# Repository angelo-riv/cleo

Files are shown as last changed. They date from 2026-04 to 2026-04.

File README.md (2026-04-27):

# Quadruped Robot

## Photos

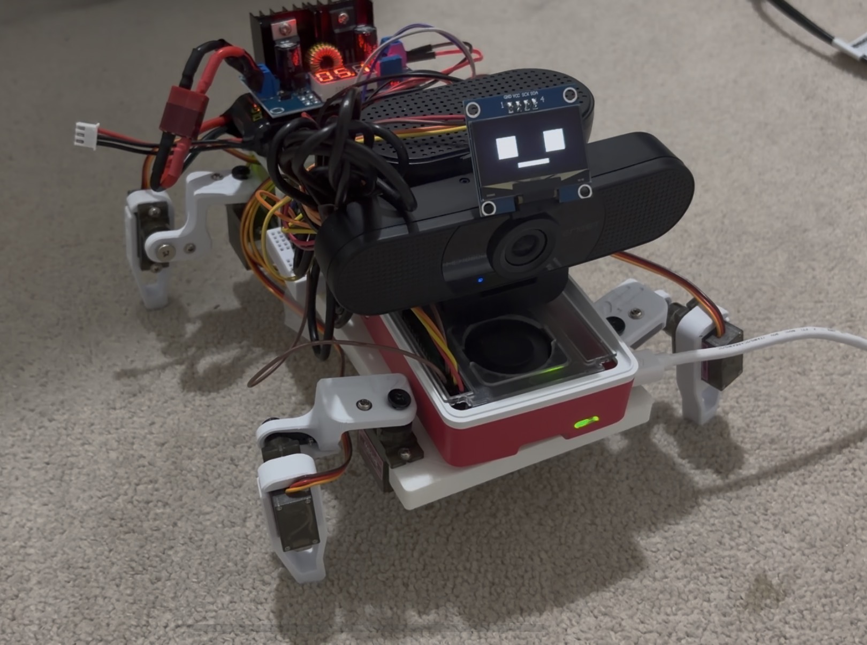
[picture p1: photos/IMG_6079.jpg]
Cleo robot photo


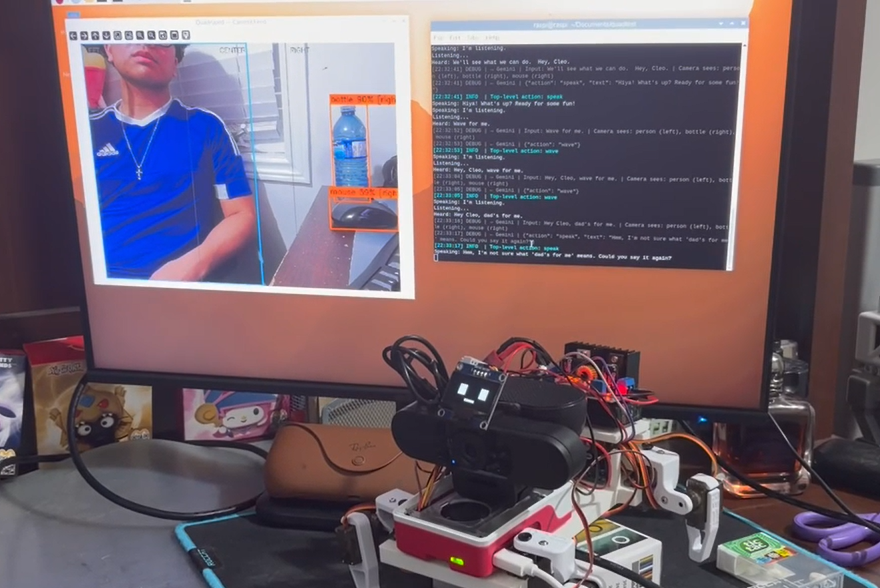
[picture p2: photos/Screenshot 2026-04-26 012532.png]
Cleo screenshot


An autonomous 4-legged robot powered by a Raspberry Pi and Google Gemini AI. Speak to it, give it missions, and it walks, looks, thinks, and talks back. Supports multiple AI personality modes switchable by voice at any time.

> For full software architecture, data flows, and code documentation see [ARCHITECTURE.md](ARCHITECTURE.md).

---

## Features

- **Voice control** — speak naturally to give missions or have a conversation
- **AI brain** — Google Gemini decides every action based on what you say and what the camera sees
- **Object detection** — camera identifies 20 object types and their position (left / center / right)
- **Walking** — creep gait using 8 servo motors across 4 legs
- **Expressive face** — OLED display shows animated faces that change based on what the robot is doing
- **Sensor awareness** — live temperature, humidity, and motion data fed to the AI
- **Switchable modes** — say "switch to search and rescue mode" and the AI's entire personality changes
- **Manual control** — keyboard-driven demo mode with live annotated camera feed for presentations

---

## Technologies Used

| Technology | What it does in this project |
|---|---|
| **Python 3** | Entire codebase |
| **Google Gemini 2.5 Flash** | AI decision engine — receives text descriptions of what the robot sees and returns the next action as JSON |
| **faster-whisper (Whisper tiny.en)** | Speech-to-text — runs fully offline on the Pi, no API key needed |
| **gTTS (Google Text-to-Speech)** | Text-to-speech — converts Gemini's responses to audio, requires internet |
| **MobileNet SSD (OpenCV DNN)** | Object detection — runs locally on the Pi, identifies objects in camera frames |
| **USB Webcam or Pi Camera** | Captures frames for object detection |
| **PCA9685 PWM driver** | Controls all 8 servo motors over I2C |
| **luma.oled + PIL** | Draws bitmap faces on the SSD1306 OLED display |
| **Adafruit CircuitPython** | Servo motor and DHT11 sensor drivers |
| **sounddevice** | Records microphone audio |
| **pygame** | Plays TTS audio through the speaker |
| **python-dotenv** | Loads API keys securely from `.env` |

---

## Hardware Required

| Part | Purpose |
|---|---|
| Raspberry Pi 4 (or 3B+) | Main computer |
| PCA9685 PWM driver board | Controls 8 servos over I2C |
| 8x servo motors | 2 per leg — hip + knee |
| USB webcam or Pi Camera Module | Object detection |
| USB microphone | Voice input |
| Speaker + USB audio adapter | Voice output |
| SSD1306 OLED display (128×64) | Face display |
| DHT11 sensor *(optional)* | Activates environment mode |
| PIR motion sensor *(optional)* | Activates security mode |
| 5V power supply | Pi + servos (servos draw significant current) |

### Wiring

| Component | Connection |
|---|---|
| PCA9685 | I2C — SDA = GPIO 2, SCL = GPIO 3, address `0x40` |
| OLED display | I2C — same bus, address `0x3C` |
| DHT11 | GPIO pin 27 |
| PIR sensor | GPIO pin 17 |
| USB webcam | Any USB port |
| USB mic + speaker | USB ports |

---

## Modes

The robot scans for attached sensor modules at boot and starts in the matching mode. Switch anytime by voice.

| Mode | Activates when | AI personality |
|---|---|---|
| `general` | No module detected | Helpful companion, conversational |
| `security` | PIR sensor on GPIO 17 | Vigilant patrol robot, threat-aware |
| `environment` | DHT11 on I2C `0x44` | Environmental monitor, flags temp/humidity anomalies |
| `search_rescue` | Voice command only | Emergency responder, systematic people-search |

**To switch by voice** — say it naturally, Gemini understands intent:
- *"Switch to search and rescue mode"*
- *"Go into security mode"*
- *"Back to general mode"*

---

## OLED Faces

The display shows animated bitmap faces. Each state has multiple variants that cycle randomly — no two consecutive looks the same.

| State | Variants | When shown |
|---|---|---|
| `idle` | Open eyes, half-asleep, mid-blink | Waiting for input |
| `thinking` | Squinted, looking sideways, looking up | Gemini is processing |
| `searching` | One-eye squint, both-eyes-wide alert | On a mission |
| `happy` | Standard smile, wink, huge eyes, star eyes, excited | Mission complete |
| `surprised` | Wide O-eyes + hollow O-mouth | Triggered manually |

---

## Setup

There are two setup paths depending on what hardware you have available:

- **[Full setup](#full-setup)** — complete robot with servos, OLED, and sensors
- **[Camera / mic / speaker only](#cameramicspeaker-only-setup)** — test voice and vision without any I2C hardware

---

## Full Setup

### 1. Flash Raspberry Pi OS

Use **Raspberry Pi Imager** → **Raspberry Pi OS (64-bit)**. In the advanced settings (gear icon):
- Set hostname, username, password
- Enable SSH
- Enter your Wi-Fi credentials

### 2. SSH into the Pi

Find the Pi's IP address from your router's device list, or from the Pi directly if you have a monitor:

```bash
hostname -I
```

Then connect from your computer:

```bash
ssh <username>@<ip-address>
# Example: ssh pi@192.168.1.42
```

If you set a hostname in Raspberry Pi Imager (e.g. `quadruped`), you can also use:

```bash
ssh <username>@quadruped.local
```

Accept the fingerprint prompt the first time. Enter the password you set in Imager.

> **Windows users** — SSH is built into PowerShell and Command Prompt on Windows 10+. No extra software needed.

### 3. Enable I2C

```bash
sudo raspi-config
```

Under **Interface Options** enable **I2C**, then reboot:

```bash
sudo reboot
```

### 4. Get the project

```bash
git clone <your-repo-url> ~/quadruped
cd ~/quadruped
```

### 5. Set up SSH key for GitHub (if cloning via SSH)

```bash
ssh-keygen -t ed25519 -C "your@email.com"
cat ~/.ssh/id_ed25519.pub
```

Copy the output and add it to GitHub under **Settings → SSH and GPG keys → New SSH key**.

Verify it works:

```bash
ssh -T git@github.com
```

### 6. Configure `.env` (Gemma 4 primary, Gemini optional fallback)

```bash
nano .env
```

```
# Primary (Ollama / Gemma 4)
CLEO_MODEL=gemma4
OLLAMA_BASE_URL=http://localhost:11434

# Optional fallback (Gemini) — only used if Ollama fails
# GEMINI_API_KEY=your_actual_key_here
# GEMINI_MODEL=gemini-2.5-flash
```

If you want the Gemini fallback, get a free key at [https://aistudio.google.com/app/apikey](https://aistudio.google.com/app/apikey). Save with `Ctrl+X` → `Y` → `Enter`.

### 7. Create a virtual environment and install dependencies

Raspberry Pi OS Trixie requires a venv — do not skip this:

```bash
python3 -m venv venv
source venv/bin/activate

sudo apt update
sudo apt install -y python3-dev portaudio19-dev libgpiod2

pip install \
  adafruit-circuitpython-pca9685 \
  adafruit-circuitpython-motor \
  adafruit-circuitpython-dht \
  opencv-python \
  luma.oled \
  Pillow \
  faster-whisper \
  sounddevice \
  gTTS \
  pygame \
  python-dotenv \
  RPi.GPIO
```

To enable the optional Gemini fallback:

```bash
pip install google-generativeai
```

> You must run `source venv/bin/activate` at the start of every new SSH session before running the robot.

### 8. Download the vision model

```bash
mkdir -p models

# Prototxt (~29 KB)
wget -O models/MobileNetSSD_deploy.prototxt \
  https://raw.githubusercontent.com/djmv/MobilNet_SSD_opencv/master/MobileNetSSD_deploy.prototxt

# Caffemodel (~23 MB) — use gdown for reliable Google Drive download
pip install gdown
gdown --id 0B3gersZ2cHIxRm5PMWRoTkdHdHc -O models/MobileNetSSD_deploy.caffemodel
```

Verify both files downloaded correctly:

```bash
ls -lh models/
# prototxt should be ~29K, caffemodel should be ~23M
```

### 9. Test audio

```bash
arecord -l    # list recording devices
aplay -l      # list playback devices
```

Test record and playback using the specific card numbers shown:

```bash
arecord -D plughw:<mic-card>,0 -d 3 -f cd test.wav && aplay -D plughw:<speaker-card>,0 test.wav
```

Set the default speaker so pygame picks it up:

```bash
nano ~/.asoundrc
```

```
defaults.pcm.card <speaker-card>
defaults.ctl.card <speaker-card>
```

If the wrong mic is selected, set `MIC_DEVICE_INDEX` in `config.py` to the correct card number.

### 10. Run

```bash
python3 main.py
```

The robot stands up and says "I'm listening."

### 11. Auto-start on boot *(optional)*

```bash
sudo nano /etc/rc.local
```

Add before `exit 0`:

```bash
cd /home/pi/quadruped && source venv/bin/activate && python3 main.py >> /home/pi/quadruped/robot.log 2>&1 &
```

---

## Camera / Mic / Speaker Only Setup

Use this path to test voice and vision without any I2C hardware (no servo driver, no OLED, no sensors). The robot runs in mock mode — servo and display commands print to the terminal instead of hitting hardware.

### 1. Flash, SSH, and get the project

Follow steps 1–6 from [Full Setup](#full-setup) above (flash OS, SSH in, get the project, add API key). Skip the raspi-config I2C step.

### 2. Create a virtual environment and install dependencies

```bash
python3 -m venv venv
source venv/bin/activate

sudo apt update
sudo apt install -y python3-dev portaudio19-dev

pip install \
  opencv-python \
  luma.oled \
  Pillow \
  faster-whisper \
  sounddevice \
  gTTS \
  pygame \
  google-generativeai \
  python-dotenv
```

### 3. Download the vision model

```bash
mkdir -p models

wget -O models/MobileNetSSD_deploy.prototxt \
  https://raw.githubusercontent.com/djmv/MobilNet_SSD_opencv/master/MobileNetSSD_deploy.prototxt

pip install gdown
gdown --id 0B3gersZ2cHIxRm5PMWRoTkdHdHc -O models/MobileNetSSD_deploy.caffemodel
```

Verify sizes (`prototxt` ~29K, `caffemodel` ~23M):

```bash
ls -lh models/
```

### 4. Enable mock mode

Open `config.py` and set:

```python
MOCK_SERVOS = True      # skips all I2C/servo/GPIO hardware
SHOW_CAMERA_FEED = False  # no display window (required when running over SSH)
CLEO_MODEL = "gemma4"
OLLAMA_BASE_URL = "http://localhost:11434"
# Optional fallback:
# GEMINI_API_KEY = "..."
# GEMINI_MODEL = "gemini-2.5-flash"
```

### 5. Test audio

```bash
arecord -l    # find your mic card number
aplay -l      # find your speaker card number
```

```bash
arecord -D plughw:<mic-card>,0 -d 3 -f cd test.wav && aplay -D plughw:<speaker-card>,0 test.wav
```

Set the default speaker:

```bash
nano ~/.asoundrc
```

```
defaults.pcm.card <speaker-card>
defaults.ctl.card <speaker-card>
```

Set `MIC_DEVICE_INDEX` in `config.py` to your mic's card number if needed.

### 6. Test camera and object detection

```bash
python3 -c "
import cv2

net = cv2.dnn.readNetFromCaffe('models/MobileNetSSD_deploy.prototxt', 'models/MobileNetSSD_deploy.caffemodel')
CLASSES = ['background','aeroplane','bicycle','bird','boat','bottle','bus','car',
           'cat','chair','cow','diningtable','dog','horse','motorbike','person',
           'pottedplant','sheep','sofa','train','tvmonitor']

cam = cv2.VideoCapture(0)
ret, frame = cam.read()
if not ret:
    print('ERROR: camera not readable')
else:
    print(f'Frame captured: {frame.shape}')
    blob = cv2.dnn.blobFromImage(cv2.resize(frame, (300,300)), 0.007843, (300,300), 127.5)
    net.setInput(blob)
    out = net.forward()
    found = [(CLASSES[int(out[0,0,i,1])], f'{out[0,0,i,2]:.0%}')
             for i in range(out.shape[2]) if out[0,0,i,2] > 0.5]
    print('Detections:', found if found else 'nothing above 50% confidence')
cam.release()
"
```

### 7. Run

```bash
python3 main.py
```

Servo and OLED commands will print as `[MOCK]` lines. Everything else (voice, camera, Gemini) runs for real.

---

## Running the Demo (Manual Control)

For presentations and demos, run `manual_control.py` instead of `main.py`. This opens a live annotated camera window on a connected monitor and lets you drive the robot with your keyboard.

```bash
python3 manual_control.py
```

> Manual control requires a connected monitor — it cannot run headless over SSH.

**Click the camera window first to capture keyboard focus, then use these controls:**

| Key | Action |
|---|---|
| `W` | Walk forward one step |
| `A` | Turn left |
| `D` | Turn right |
| `S` | Stand / stop |
| `SPACE` | Ask Gemini what it currently sees — speaks the answer aloud and shows it on screen |
| `1` | Switch to General mode |
| `2` | Switch to Security mode |
| `3` | Switch to Environment mode |
| `4` | Switch to Search & Rescue mode |
| `F` | Cycle the OLED to a random happy face |
| `Q` or `ESC` | Quit cleanly |

The camera window overlays the current mode, last action, last LLM response, and live sensor readings directly on the feed.

---

## Configuration Reference

| Setting | What it controls | Default |
|---|---|---|
| `OLLAMA_BASE_URL` | Ollama server URL (primary LLM) | `http://localhost:11434` |
| `CLEO_MODEL` | Ollama model name (primary LLM) | `gemma4` |
| `GEMINI_API_KEY` | Enables Gemini fallback if set | *(blank)* |
| `GEMINI_MODEL` | Gemini model used for fallback | `gemini-2.5-flash` |
| `WHISPER_MODEL` | STT model size | `tiny.en` |
| `MIC_DEVICE_INDEX` | USB mic card number (`None` = auto) | `None` |
| `CAMERA_RESOLUTION` | Capture resolution | `(640, 480)` |
| `DETECTION_CONFIDENCE_THRESHOLD` | Min confidence to report an object | `0.5` |
| `SHOW_CAMERA_FEED` | Show annotated feed on monitor (disable over SSH) | `True` |
| `MOCK_SERVOS` | Skip all I2C/servo/GPIO hardware | `False` |
| `GAIT_STEP_ANGLE` | Hip swing per step (degrees) | `20` |
| `GAIT_LIFT_ANGLE` | Knee lift per step (degrees) | `30` |
| `GAIT_STEP_DELAY` | Pause between gait phases (seconds) | `0.15` |
| `PCA9685_ADDRESS` | I2C address of servo driver | `0x40` |
| `OLED_I2C_ADDRESS` | I2C address of OLED | `0x3C` |
| `PIR_GPIO_PIN` | GPIO pin for PIR sensor | `17` |
| `DHT11_GPIO_PIN` | GPIO pin for DHT11 sensor | `27` |

---

## Security Notes

- `.env` is in `.gitignore` — it will never be committed
- Gemini fallback is optional — if `GEMINI_API_KEY` is missing, the robot still runs (Gemma 4 via Ollama only)
- Never paste your API key into chat, issues, or log files
- `robot.log` does not record API keys or audio transcripts

---

## Known Limitations

- **gTTS needs internet** — for fully offline TTS, swap `gTTS` for `pyttsx3` in `voice/tts.py`
- **Whisper has a 1–2s delay** — after you stop speaking, transcription takes a moment on Pi 4
- **MobileNet SSD recognises 20 object classes only** — it cannot identify objects outside that list
- **LLM chat history is in-memory** — resets on restart or mode change
- **`SHOW_CAMERA_FEED = True` crashes over SSH** — set it to `False` when running headless

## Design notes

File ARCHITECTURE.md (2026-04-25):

# Software Architecture

Technical documentation for the quadruped robot codebase — data flows, execution loops, component responsibilities, and design decisions.

> For setup instructions, hardware, features, and demo controls see [README.md](README.md).

---

## System Layers

```
╔══════════════════════════════════════════════════════════════════╗
║                         YOU (the human)                          ║
║                  speak ↓              ↑ hear                     ║
╚══════════════════════════╤═══════════════════════════════════════╝
                           │
╔══════════════════════════▼═══════════════════════════════════════╗
║                      HARDWARE LAYER                              ║
║                                                                  ║
║  [USB Mic] [Pi Camera] [PIR Sensor] [DHT11] [Speaker]           ║
║  [8x Servos via PCA9685]  [SSD1306 OLED]                        ║
╚══════════════════════════╤═══════════════════════════════════════╝
                           │ GPIO / I2C / CSI / USB
╔══════════════════════════▼═══════════════════════════════════════╗
║                      SOFTWARE LAYER (Python)                     ║
║                                                                  ║
║  ┌──────────────────────────────────────────────────────────┐   ║
║  │                    brain/agent.py                         │   ║
║  │             (master orchestrator — runs forever)          │   ║
║  └───┬──────────┬───────────┬──────────┬──────────┬─────────┘   ║
║      │          │           │          │          │              ║
║  ┌───▼───┐  ┌───▼───┐  ┌───▼───┐  ┌───▼───┐  ┌───▼──────────┐ ║
║  │voice/ │  │vision/│  │motion/│  │display│  │  modules/    │ ║
║  │stt.py │  │detect │  │gait.py│  │oled.py│  │  pir.py      │ ║
║  │tts.py │  │or.py  │  │servo_ │  │faces/ │  │  dht11.py    │ ║
║  │       │  │       │  │ctrl.py│  │       │  │  detector.py │ ║
║  └───┬───┘  └───┬───┘  └───────┘  └───────┘  └──────────────┘ ║
║      │          │                                               ║
║  ┌───▼──────────▼─────────────────────────────────────────┐    ║
║  │                    brain/llm.py                         │    ║
║  │   (packages inputs → sends to Gemini → parses JSON)    │    ║
║  └───────────────────────────┬─────────────────────────────┘   ║
╚══════════════════════════════╤══════════════════════════════════╝
                               │ HTTPS (Gemini API)
╔══════════════════════════════▼═══════════════════════════════════╗
║                      GOOGLE GEMINI (cloud AI)                    ║
║   Receives: user speech + camera detections + sensor readings    ║
║   Returns:  one JSON action  e.g. {"action": "walk_forward"}     ║
╚══════════════════════════════════════════════════════════════════╝
```

---

## Project Structure

```
quadruped/
├── main.py                  # Entry point — creates and runs Agent
├── manual_control.py        # Demo mode — keyboard control + live camera feed
├── config.py                # All settings, loaded from .env + hardware constants
├── setup.sh                 # One-time install script for Raspberry Pi
├── .env                     # Secret API keys (never committed)
├── .gitignore               # Excludes .env, model weights, pycache
│
├── brain/
│   ├── agent.py             # Master orchestrator — boot, main loop, mission loop
│   └── llm.py               # Gemini: mode prompts, persistent chat session, JSON parsing
│
├── motion/
│   ├── servo_controller.py  # Low-level: sets angles on individual joints via PCA9685
│   └── gait.py              # High-level: coordinates 4 legs for walking and turning
│
├── vision/
│   └── detector.py          # Pi Camera + MobileNet SSD: detects objects with position
│
├── voice/
│   ├── stt.py               # USB mic → Whisper AI → text (fully offline)
│   └── tts.py               # Text → Google TTS → speaker audio
│
├── display/
│   ├── oled.py              # Renders bitmap faces on SSD1306 OLED, random variant selection
│   └── faces/
│       ├── idle.py          # Open eyes, flat mouth
│       ├── idle_sleepy.py   # Half-closed eyes
│       ├── idle_blink.py    # Mid-blink slit eyes
│       ├── thinking.py      # Squinted eyes
│       ├── thinking_sideways.py  # Eyes shifted right
│       ├── thinking_up.py   # Eyes shifted upward
│       ├── searching.py     # One wide, one squinted
│       ├── searching_alert.py    # Both eyes wide open
│       ├── happy.py         # Standard smile
│       ├── happy_wink.py    # Wink + smile
│       ├── happy_big.py     # Oversized eyes + wide smile
│       ├── happy_star.py    # Cross/star-shaped eyes + smile
│       ├── excited.py       # Eyebrows + big eyes + extra-wide smile
│       └── surprised.py     # Huge square eyes + hollow O-mouth
│
├── modules/
│   ├── detector.py          # I2C bus scan at boot → returns starting mode string
│   ├── dht11.py             # DHT11 driver → {temperature, humidity}
│   └── pir.py               # PIR driver → motion_detected bool
│
└── utils/
    └── logger.py            # Colour-coded terminal logger with timestamps and levels
```

---

## Component Responsibilities

| File | Role | Inputs | Outputs |
|---|---|---|---|
| `main.py` | Entry point | — | Creates and runs `Agent` |
| `brain/agent.py` | Orchestrator | All sensor/voice/vision data | Commands to all subsystems |
| `brain/llm.py` | AI interface | Speech + detections + sensor data + mode | JSON action dict |
| `voice/stt.py` | Speech-to-text | USB mic audio (5s window) | Transcribed string |
| `voice/tts.py` | Text-to-speech | String | Audio played through speaker |
| `vision/detector.py` | Object detection | Camera frame | `[{label, position, confidence, bbox}]` |
| `motion/servo_controller.py` | Joint control | Joint name + angle | PWM signal via PCA9685 |
| `motion/gait.py` | Walking | Action string | Sequence of joint angle commands |
| `display/oled.py` | Face display | Face state string | Bitmap rendered to OLED |
| `modules/detector.py` | Mode detection | I2C bus scan | Mode string |
| `modules/pir.py` | Motion sensing | GPIO pin 17 | `True` / `False` |
| `modules/dht11.py` | Environment sensing | GPIO pin 27 | `{temperature, humidity}` |
| `utils/logger.py` | Logging | Message + level string | Colour-coded terminal line |
| `config.py` | Configuration | `.env` file | Constants used by all modules |

---

## Boot Sequence

```
python3 main.py
       │
       ▼
Agent.__init__()
       │
       ├──► ServoController()
       │         └── Connects to PCA9685 over I2C (address 0x40)
       │         └── Creates 8 servo objects (hips + knees for each leg)
       │
       ├──► GaitController(servo_controller)
       │         └── Stores servo reference, loads standing pose from config
       │
       ├──► VisionDetector()
       │         └── Loads MobileNet SSD model files into OpenCV DNN
       │         └── Starts Raspberry Pi Camera via picamera2
       │
       ├──► OLEDDisplay()
       │         └── Connects to SSD1306 over I2C (address 0x3C)
       │
       ├──► SpeechToText()
       │         └── Loads Whisper "tiny.en" model into CPU memory (~75MB)
       │
       ├──► TextToSpeech()
       │         └── Initialises pygame audio mixer
       │
       ├──► ModuleDetector()
       │         └── Scans I2C bus for known addresses
       │         └── Returns: "environment" (DHT11) | "security" (default)
       │
       ├──► PIRSensor()   [optional — skipped gracefully if absent]
       │         └── Configures GPIO pin 17 as input
       │
       └──► DHT11Sensor() [optional — skipped gracefully if absent]
                 └── Configures GPIO pin 27 as input

Agent.run()
       │
       ├──► sc.stand()              → all 8 servos go to standing pose
       ├──► oled.show("idle")       → OLED renders idle face variant
       ├──► module.detect()         → returns active mode string
       ├──► llm.reset_session(mode) → creates Gemini chat session with mode prompt
       └──► tts.speak("Ready. [mode] mode active.")
```

---

## Main Loop (idle / conversation)

Runs forever after boot. The robot stays here until Gemini returns a movement action.

```
                    ┌──────────────────────────────────┐
                    │         MAIN LOOP (forever)       │
                    └──────────────────┬───────────────┘
                                       │
                              oled.show("idle")
                                       │
                         tts.speak("I'm listening.")
                         [first pass only, or after
                          mission / mode switch ends]
                                       │
                                       ▼
                         ┌─────────────────────────┐
                         │  stt.listen(duration=5)  │
                         │  USB mic records 5 secs  │
                         │  Whisper transcribes it  │
                         └───────────┬─────────────┘
                                     │
                          ┌──────────▼──────────┐
                          │  user_input empty?   │
                          └──────────┬──────────┘
                              yes ◄──┴──► no
                               │              │
                    [refresh camera feed]  oled.show("thinking")
                    [if SHOW_CAMERA_FEED]       │
                    [then loop back]    ┌───────▼────────────────┐
                                        │  _detect()             │
                                        │  Camera captures frame │
                                        │  MobileNet runs        │
                                        │  Frame shown on monitor│
                                        │  if SHOW_CAMERA_FEED   │
                                        └───────┬────────────────┘
                                                │
                                        ┌───────▼────────────────┐
                                        │  _read_sensors()        │
                                        │  PIR → motion: bool     │
                                        │  DHT11 → temp, humidity │
                                        └───────┬────────────────┘
                                                │
                                        ┌───────▼────────────────┐
                                        │  llm.decide(           │
                                        │    user_input,          │
                                        │    detections,          │
                                        │    mode,                │
                                        │    sensor_data          │
                                        │  )                     │
                                        │                        │
                                        │  Message sent:         │
                                        │  "Input: [speech]      │
                                        │   Camera sees: [objs]  │
                                        │   Sensors: [readings]" │
                                        │                        │
                                        │  Gemini replies: JSON  │
                                        │  History preserved in  │
                                        │  chat session          │
                                        └───────┬────────────────┘
                                                │
                                   ┌────────────▼────────────────┐
                                   │  action = decision["action"] │
                                   └──┬──────┬──────┬──────┬─────┘
                                      │      │      │      │
                                   "speak" "set_ "stop" movement
                                      │    mode"    │   action
                                      │      │      │      │
                                tts.speak() │  sc.stand()  │
                                      │  switch    │  _run_mission()
                                      │  mode +    │
                                      │  new chat  │
                                      │  session   │
                                      └─────┴──────┘
                                             │
                                          (loop back)
```

---

## Mission Execution Flow

Triggered when Gemini returns a movement action. The robot navigates autonomously, querying Gemini every step, until `complete` or 30 steps.

```
_run_mission(mission, mode, first_action)
       │
       ├──► oled.show("searching")
       ├──► gait.execute(first_action)   ← first action already decided, run immediately
       │
       │         ┌────────────────────────────────────────────┐
       │         │      MISSION LOOP (up to 29 more steps)     │
       │         └──────────────────┬─────────────────────────┘
       │                            │
       │                   oled.show("thinking")
       │                            │
       │             ┌──────────────▼──────────────┐
       │             │  _detect()                   │
       │             │  _read_sensors()             │
       │             │  llm.decide(...)             │
       │             │  → full chat history + new   │
       │             │    frame + live sensor data  │
       │             └──────────────┬──────────────┘
       │                            │
       │             ┌──────────────▼──────────────┐
       │             │    action?                   │
       │             └──┬──────┬──────┬──────┬──────┘
       │                │      │      │      │
       │           "complete" "speak" "set_ movement
       │                │      │      mode"  │
       │                │      │      │      │
       │          oled("happy")│  switch  gait.execute()
       │          tts("Mission"│  mode    oled("searching")
       │             complete")│  return  (next step)
       │          sc.stand()   │
       │          return mode  │
       │                  tts.speak(text)
       │                  oled("searching")
       │                  (continue loop)
       │
       └──► [30 steps, no complete]
                 tts.speak("I could not complete the mission.")
                 sc.stand()
                 oled.show("idle")
                 return mode
```

---

## Mode Switching Flow

Triggered by voice from either the main loop or mid-mission. Gemini issues the `set_mode` action itself based on what you say.

```
You say: "Switch to search and rescue mode"
                    │
                    ▼
          llm.decide() → Gemini sees speech + camera + sensors
                    │
                    ▼
          Gemini returns:
          {
            "action": "set_mode",
            "mode":   "search_rescue",
            "text":   "Switching to search and rescue mode."
          }
                    │
                    ▼
          agent._handle_set_mode()
                    │
                    ├──► tts.speak(text)
                    ├──► llm.reset_session("search_rescue")
                    │         └── New Gemini chat session
                    │         └── System prompt: emergency responder personality
                    │         └── Previous history cleared
                    └──► mode = "search_rescue"
```

---

## What Gemini Receives Each Step

Every `llm.decide()` call sends one text message into the persistent chat session:

```
Input: find the person
Camera sees: person (center), bottle (left)
Sensor readings: PIR motion detected: True | Temperature: 24.5°C | Humidity: 55.0%
```

Gemini replies with exactly one JSON object chosen from the valid action set:

```json
{"action": "walk_forward"}
{"action": "speak", "text": "I see a person ahead, should I approach?"}
{"action": "complete"}
{"action": "set_mode", "mode": "search_rescue", "text": "Switching to search and rescue mode."}
```

Valid actions: `walk_forward`, `turn_left`, `turn_right`, `stop`, `complete`, `speak`, `set_mode`

The chat session retains full message history — Gemini has context about everything said and seen since the session started or last mode switch.

---

## Mode Prompts

Each mode gives Gemini a distinct system prompt loaded at session creation. All share the same base navigation and response format rules.

| Mode | Personality |
|---|---|
| `general` | Helpful curious companion. Navigates on request, converses freely. |
| `security` | Vigilant patrol robot. Treats unknowns as threats. Reports motion immediately. Brief, professional responses. |
| `environment` | Analytical environmental monitor. Always acknowledges sensor readings. Flags anomalies (temp > 35°C / < 10°C, humidity > 80% / < 20%). |
| `search_rescue` | Emergency responder. Systematic scan pattern. Never declares complete until a person is centered in frame. Life-or-death urgency. |

---

## Vision Pipeline

The camera never sends images to Gemini. All computer vision runs locally on the Pi.

```
1. Camera captures one frame (640×480)
        │
        ▼
2. Frame resized to 300×300 and normalised
        │
        ▼
3. MobileNet SSD runs on Pi CPU
   → bounding boxes + class labels + confidence scores
        │
        ▼
4. Results filtered: confidence must exceed threshold (default 0.5)
        │
        ▼
5. Horizontal center of each box determines position:
   cx < 213px  → "left"
   cx > 427px  → "right"
   otherwise   → "center"
        │
        ▼
6. Returns: [{"label": "person", "position": "center", "confidence": 0.87, "bbox": (x1,y1,x2,y2)}]
        │
        ▼
7. Agent converts to plain text → sent to Gemini as part of the message
```

**If `SHOW_CAMERA_FEED = True`:** bounding boxes, labels, confidence scores, and position zone markers are drawn onto the frame and displayed in a resizable OpenCV window.

### Detectable Object Classes (MobileNet SSD)

`person`, `bird`, `cat`, `dog`, `horse`, `cow`, `sheep`, `bottle`, `chair`, `sofa`, `diningtable`, `pottedplant`, `tvmonitor`, `car`, `bus`, `bicycle`, `motorbike`, `boat`, `aeroplane`, `train`

---

## Gait Mechanics

Each leg has two servo joints — a **hip** (swings the leg forward/backward) and a **knee** (lifts the foot). The creep gait moves one leg at a time so three legs are always on the ground.

```
Step order: front_left → rear_right → front_right → rear_left  (repeat)

Each leg per step:
  1. Knee lifts    — foot leaves ground
  2. Hip swings    — leg moves in direction of travel
  3. Knee plants   — foot returns to ground
  4. Hip returns   — neutral position, body weight shifts
```

Turning rotates the body in place: one side swings backward while the other swings forward.

---

## OLED Face System

Each face file defines a `BITMAP` — a list of `(x1, y1, x2, y2)` rectangle coordinates on a 128×64 pixel canvas.

`oled.show(state)` works as follows:
1. Looks up the face group for the requested state
2. Picks a random variant from the group, avoiding the previous one
3. Creates a blank 1-bit PIL image (all black)
4. Draws each rectangle as white pixels
5. Pushes the image to the SSD1306 display over I2C

Face groups and their variants:

| State | Variants |
|---|---|
| `idle` | `idle`, `idle_sleepy`, `idle_blink` |
| `thinking` | `thinking`, `thinking_sideways`, `thinking_up` |
| `searching` | `searching`, `searching_alert` |
| `happy` | `happy`, `happy_wink`, `happy_big`, `happy_star`, `excited` |
| `surprised` | `surprised` |

---

## Speech Systems

### STT — Speech to Text (`voice/stt.py`)
- Uses `faster-whisper` running the `tiny.en` Whisper model locally on the Pi CPU
- Records 5 seconds of audio via `sounddevice` from the USB microphone
- Transcribes entirely offline — no internet, no API key
- Model is downloaded once (~75MB) during setup
- Typical transcription time on Pi 4: 1–2 seconds after recording ends

### TTS — Text to Speech (`voice/tts.py`)
- Uses `gTTS` (Google Text-to-Speech) — sends text to Google's servers, receives an MP3
- Plays audio through the speaker via `pygame.mixer`
- **Requires internet connection** — no API key needed
- For fully offline TTS, replace with `pyttsx3` in `voice/tts.py`

---

## Security

- `.env` is in `.gitignore` and will never be committed
- `config.py` uses `os.environ["GEMINI_API_KEY"]` — crashes immediately on startup if key is missing
- No API keys or audio content are written to `robot.log`
- Sensor readings and Gemini responses are logged at DEBUG level only

---

## Known Limitations

- **gTTS requires internet** — swap for `pyttsx3` in `voice/tts.py` for offline operation
- **Whisper STT has 1–2s delay** — after speaking stops, transcription takes time on Pi 4
- **MobileNet SSD is fixed at 20 classes** — cannot identify objects outside the trained set
- **Gemini chat history is in-memory only** — resets on restart or mode switch
- **Vision is frame-by-frame** — no continuous video stream; camera only samples during decision steps

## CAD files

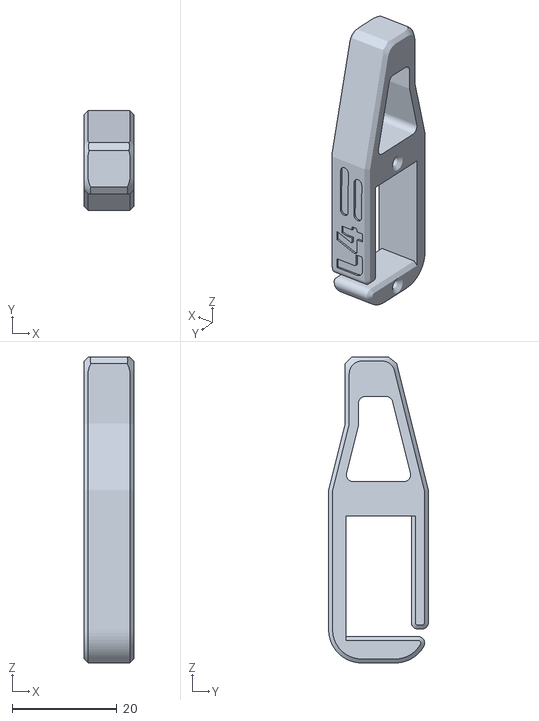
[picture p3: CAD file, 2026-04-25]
CAD/L4-v117.stl
9.53 x 19.0 x 58.4

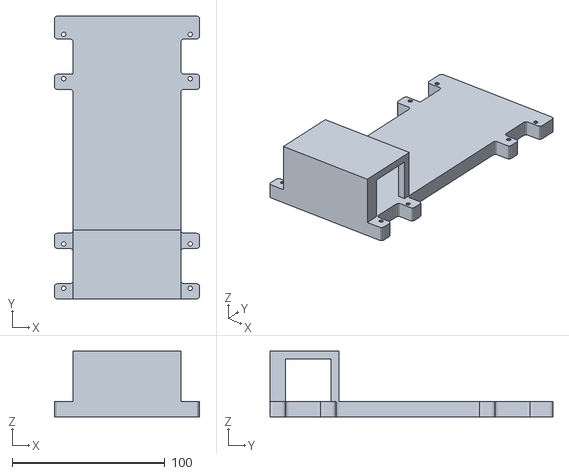
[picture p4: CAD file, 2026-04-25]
CAD/Internal frame.stl
95.0 x 185.0 x 43.0

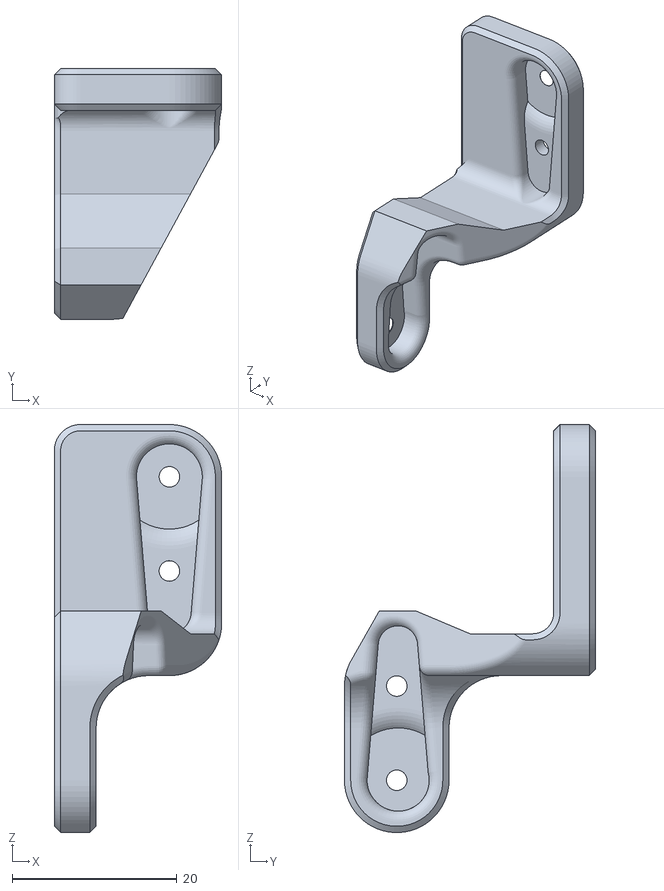
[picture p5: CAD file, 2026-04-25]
CAD/L1-v117.stl
20.3 x 30.5 x 49.5

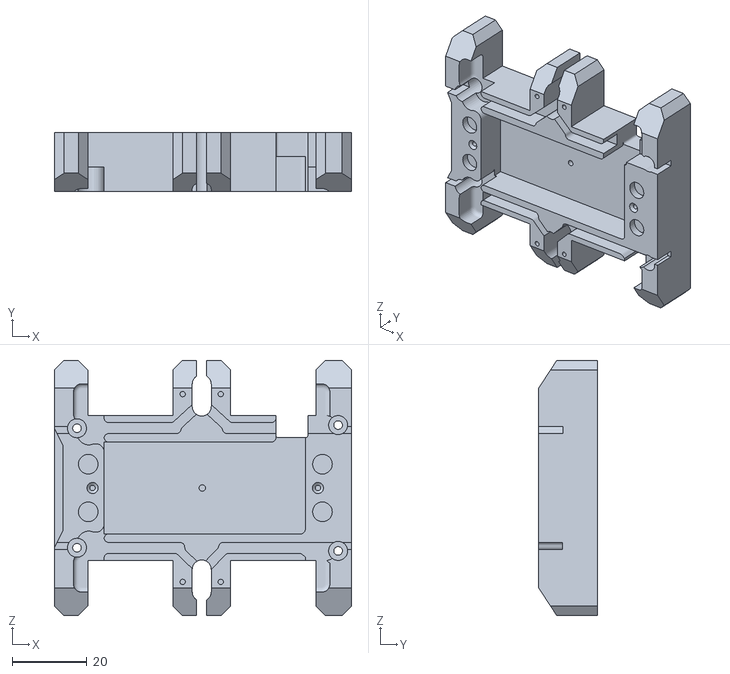
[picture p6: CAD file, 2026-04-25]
CAD/Internal-Frame-v117.stl
79.2 x 15.7 x 68.1

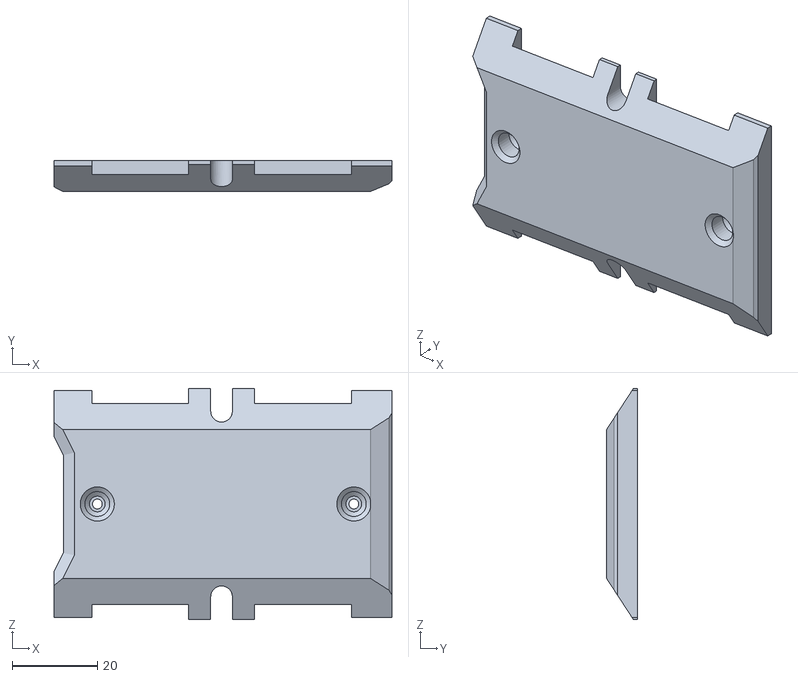
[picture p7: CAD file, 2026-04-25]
CAD/Bottom-Cover-v117.stl
79.2 x 7.27 x 54.2

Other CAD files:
CAD/L3-v117.stl
CAD/R4-v117.stl
CAD/R3-v117.stl
CAD/L2-v117.stl
CAD/R1-v117.stl
CAD/R2-v117.stl
CAD/Battery.ipt
CAD/Internal frame.ipt

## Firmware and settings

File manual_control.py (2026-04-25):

"""
Manual Control — Demo interface for judges / presentations.

Run this INSTEAD of main.py when you want manual control.
Shows a live annotated camera feed on the connected monitor.
Keyboard controls let you move the robot, query Gemini, and switch modes.

Usage:
    python3 manual_control.py

Controls (click the camera window first to capture keyboard focus):
    W          Walk forward one step
    A          Turn left
    D          Turn right
    S          Stand / stop
    SPACE      Ask Gemini: "What do you see?" — speaks and displays the answer
    1          Switch to general mode
    2          Switch to security mode
    3          Switch to environment mode
    4          Switch to search & rescue mode
    F          Cycle OLED to a random happy face
    Q / ESC    Quit
"""

import sys
import cv2
import numpy as np

import config
from motion.servo_controller import ServoController
from motion.gait import GaitController
from vision.detector import VisionDetector
from display.oled import OLEDDisplay
from voice.tts import TextToSpeech
from modules.pir import PIRSensor
from modules.dht11 import DHT11Sensor
from brain import llm
from utils.logger import log

# ---------------------------------------------------------------------------
# Constants
# ---------------------------------------------------------------------------

WINDOW = "Quadruped — Manual Control"

MODE_KEYS = {
    ord('1'): "general",
    ord('2'): "security",
    ord('3'): "environment",
    ord('4'): "search_rescue",
}

CONTROLS_TEXT = [
    "W  — Walk forward",
    "A  — Turn left",
    "D  — Turn right",
    "S  — Stand / stop",
    "SPACE — Ask Gemini",
    "1  — General mode",
    "2  — Security mode",
    "3  — Environment mode",
    "4  — Search & rescue",
    "F  — Happy face",
    "Q/ESC — Quit",
]

# Overlay colours (BGR)
_PANEL_BG    = (20, 20, 20)
_TEXT_COLOUR = (220, 220, 220)
_KEY_COLOUR  = (80, 220, 80)
_MODE_COLOUR = (0, 200, 255)
_RESP_COLOUR = (255, 200, 80)
_WARN_COLOUR = (0, 80, 255)


# ---------------------------------------------------------------------------
# Overlay drawing helpers
# ---------------------------------------------------------------------------

def _draw_panel(img: np.ndarray, x: int, y: int, w: int, h: int, alpha: float = 0.6):
    """Draw a semi-transparent dark rectangle."""
    overlay = img.copy()
    cv2.rectangle(overlay, (x, y), (x + w, y + h), _PANEL_BG, -1)
    cv2.addWeighted(overlay, alpha, img, 1 - alpha, 0, img)


def _put(img, text, pos, colour=_TEXT_COLOUR, scale=0.45, thickness=1):
    cv2.putText(img, text, pos, cv2.FONT_HERSHEY_SIMPLEX, scale, colour, thickness, cv2.LINE_AA)


def _draw_controls(img: np.ndarray):
    """Draw the keyboard controls legend in the top-right corner."""
    panel_x = img.shape[1] - 220
    panel_h = len(CONTROLS_TEXT) * 18 + 28
    _draw_panel(img, panel_x - 8, 4, 224, panel_h)
    _put(img, "CONTROLS", (panel_x, 20), _KEY_COLOUR, 0.5, 1)
    for i, line in enumerate(CONTROLS_TEXT):
        _put(img, line, (panel_x, 38 + i * 18))


def _draw_status(img: np.ndarray, mode: str, last_response: str, last_action: str):
    """Draw current mode, last action, and last Gemini response at the bottom."""
    h, w = img.shape[:2]
    _draw_panel(img, 0, h - 70, w, 70)
    _put(img, f"MODE: {mode.upper().replace('_', ' ')}", (10, h - 52), _MODE_COLOUR, 0.5, 1)
    _put(img, f"LAST ACTION: {last_action}", (10, h - 34), _KEY_COLOUR, 0.45)
    # Wrap long response text
    response_display = last_response[:90] + "…" if len(last_response) > 90 else last_response
    _put(img, f"GEMINI: {response_display}", (10, h - 14), _RESP_COLOUR, 0.42)


def _draw_sensor_overlay(img: np.ndarray, sensor_data: dict):
    """Draw live sensor readings in bottom-right if present."""
    if not sensor_data:
        return
    lines = []
    if "motion_detected" in sensor_data:
        colour = _WARN_COLOUR if sensor_data["motion_detected"] else _TEXT_COLOUR
        lines.append(("MOTION DETECTED!" if sensor_data["motion_detected"] else "No motion", colour))
    if "temperature" in sensor_data:
        lines.append((f"Temp: {sensor_data['temperature']}°C", _TEXT_COLOUR))
    if "humidity" in sensor_data:
        lines.append((f"Humidity: {sensor_data['humidity']}%", _TEXT_COLOUR))
    if not lines:
        return
    h, w = img.shape[:2]
    base_x = w - 220
    base_y = img.shape[0] - 80 - len(lines) * 18
    _draw_panel(img, base_x - 8, base_y - 14, 224, len(lines) * 18 + 18)
    for i, (text, col) in enumerate(lines):
        _put(img, text, (base_x, base_y + i * 18), col, 0.45)


# ---------------------------------------------------------------------------
# Hardware initialisation
# ---------------------------------------------------------------------------

def _try_init(cls, name: str):
    try:
        obj = cls()
        log(f"{name} initialised.", level="info")
        return obj
    except Exception as e:
        log(f"{name} not available: {e}", level="warn")
        return None


def _read_sensors(pir, dht) -> dict:
    data = {}
    if pir:
        try:
            data["motion_detected"] = pir.motion_detected()
        except Exception:
            pass
    if dht:
        try:
            reading = dht.read()
            if reading.get("temperature") is not None:
                data["temperature"] = reading["temperature"]
            if reading.get("humidity") is not None:
                data["humidity"] = reading["humidity"]
        except Exception:
            pass
    return data


# ---------------------------------------------------------------------------
# Main
# ---------------------------------------------------------------------------

def main():
    log("=== Manual Control Mode ===", level="info")

    # Init hardware
    log("Initialising servos...", level="info")
    sc   = ServoController()
    gait = GaitController(sc)

    log("Initialising vision...", level="info")
    vision = VisionDetector()

    log("Initialising display...", level="info")
    oled = OLEDDisplay()

    log("Initialising TTS...", level="info")
    tts = TextToSpeech()

    pir = _try_init(PIRSensor,   "PIR sensor")
    dht = _try_init(DHT11Sensor, "DHT11 sensor")

    # Starting mode
    mode          = "general"
    last_response = "—"
    last_action   = "stand"

    llm.reset_session(mode)
    sc.stand()
    oled.show("idle")
    tts.speak("Manual control active. General mode.")

    # Open camera window
    cv2.namedWindow(WINDOW, cv2.WINDOW_NORMAL)
    cv2.resizeWindow(WINDOW, 960, 720)
    log("Camera window open. Click it and use keyboard controls.", level="info")

    try:
        while True:
            # Always capture and display a fresh frame
            detections, frame = vision.detect_with_frame()
            sensor_data       = _read_sensors(pir, dht)

            # Draw overlays
            _draw_controls(frame)
            _draw_status(frame, mode, last_response, last_action)
            _draw_sensor_overlay(frame, sensor_data)

            cv2.imshow(WINDOW, frame)
            key = cv2.waitKey(30) & 0xFF  # ~33 fps loop, non-blocking key read

            # ----------------------------------------------------------------
            # Movement keys
            # ----------------------------------------------------------------
            if key == ord('w'):
                log("Manual: walk_forward", level="info")
                last_action = "walk_forward"
                oled.show("searching")
                gait.execute("walk_forward")
                oled.show("idle")

            elif key == ord('a'):
                log("Manual: turn_left", level="info")
                last_action = "turn_left"
                oled.show("searching")
                gait.execute("turn_left")
                oled.show("idle")

            elif key == ord('d'):
                log("Manual: turn_right", level="info")
                last_action = "turn_right"
                oled.show("searching")
                gait.execute("turn_right")
                oled.show("idle")

            elif key == ord('s'):
                log("Manual: stand", level="info")
                last_action = "stand"
                sc.stand()
                oled.show("idle")

            # ----------------------------------------------------------------
            # Gemini query
            # ----------------------------------------------------------------
            elif key == ord(' '):
                log("Manual: querying Gemini...", level="info")
                oled.show("thinking")
                last_action = "ask Gemini"

                decision = llm.decide(
                    user_input   = "Describe what you currently see in one short sentence.",
                    detections   = detections,
                    mode         = mode,
                    sensor_data  = sensor_data,
                )

                text = decision.get("text", "")
                if not text:
                    # If Gemini returned a movement action instead of speak,
                    # ask it more directly as a follow-up
                    follow_up = llm.decide(
                        user_input  = "Just tell me what you see. Use the speak action.",
                        detections  = detections,
                        mode        = mode,
                        sensor_data = sensor_data,
                    )
                    text = follow_up.get("text", "I see: " + (
                        ", ".join(d["label"] for d in detections) or "nothing"
                    ))

                last_response = text
                tts.speak(text)
                oled.show("happy")
                log(f"Gemini response: {text}", level="info")

            # ----------------------------------------------------------------
            # Mode switching
            # ----------------------------------------------------------------
            elif key in MODE_KEYS:
                new_mode = MODE_KEYS[key]
                if new_mode != mode:
                    log(f"Mode switch: {mode} → {new_mode}", level="info")
                    mode        = new_mode
                    last_action = f"set mode: {new_mode}"
                    llm.reset_session(new_mode)
                    oled.show("thinking")
                    announce = f"Switching to {new_mode.replace('_', ' ')} mode."
                    last_response = announce
                    tts.speak(announce)
                    oled.show("idle")

            # ----------------------------------------------------------------
            # Face cycle
            # ----------------------------------------------------------------
            elif key == ord('f'):
                oled.show("happy")
                last_action = "face cycle"

            # ----------------------------------------------------------------
            # Quit
            # ----------------------------------------------------------------
            elif key in (ord('q'), 27):  # Q or ESC
                log("Quitting manual control.", level="info")
                break

    finally:
        sc.stand()
        oled.show("idle")
        vision.stop()
        cv2.destroyAllWindows()
        log("Manual control stopped.", level="info")


if __name__ == "__main__":
    main()

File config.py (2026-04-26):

import os
from dotenv import load_dotenv

load_dotenv()

# --- Servo channels (PCA9685 channel index per joint) ---
# Ch 0  = R1 = front_right_hip
# Ch 11 = R2 = front_right_knee
# Ch 2  = L1 = front_left_hip
# Ch 3  = L2 = front_left_knee
# Ch 4  = R4 = rear_right_knee
# Ch 12 = R3 = rear_right_hip  (NOT WORKING — investigate)
# Ch 9  = L3 = rear_left_hip
# Ch 7  = L4 = rear_left_knee
SERVO_CHANNELS = {
    "front_right_hip":  0,
    "front_right_knee": 11,
    "front_left_hip":   2,
    "front_left_knee":  3,
    "rear_right_knee":  4,
    "rear_right_hip":   12,
    "rear_left_hip":    9,
    "rear_left_knee":   7,
}

# --- Per-joint angle limits (degrees) ---
# Measured from physical tuning — do not exceed these or servos will strain
SERVO_LIMITS = {
    "front_right_hip":  (50,  160),   # R1: 50=front, 160=back
    "front_right_knee": (70,  110),   # R2: 70=front, 110=back
    "front_left_hip":   (10,  120),   # L1: 10=back,  120=front
    "front_left_knee":  (80,  150),   # L2: 80=back,  150=front
    "rear_right_knee":  (30,  180),   # R4: 30=down,  180=up
    "rear_right_hip":   (90,  90),    # R3: NOT WORKING — locked at 90 for safety
    "rear_left_hip":    (30,  180),   # L3: 30=down,  180=up
    "rear_left_knee":   (0,   140),   # L4: 0=up,     140=down
}

# --- Standing pose (degrees per joint) ---
# 90° = upright for all joints
STAND_POSE = {
    "front_right_hip":  90,
    "front_right_knee": 90,
    "front_left_hip":   90,
    "front_left_knee":  90,
    "rear_right_knee":  90,
    "rear_right_hip":   90,   # R3 not working — wiring issue
    "rear_left_hip":    90,
    "rear_left_knee":   90,
}

# --- Gait parameters ---
GAIT_STEP_ANGLE = 20    # degrees hip swings per step
GAIT_LIFT_ANGLE = 30    # degrees knee lifts per step
GAIT_STEP_DELAY = 0.15  # seconds between each phase

# --- PCA9685 ---
I2C_BUS         = 1
PCA9685_ADDRESS = 0x40
PWM_FREQUENCY   = 50    # Hz — standard for servos

# --- Development flags ---
# Set True to skip real I2C/servo hardware and print commands to the terminal instead.
MOCK_SERVOS = False

# --- Vision ---
CAMERA_RESOLUTION  = (640, 480)
DETECTION_CONFIDENCE_THRESHOLD = 0.4

# --- LLM ---
OLLAMA_BASE_URL = os.environ.get("OLLAMA_BASE_URL", "http://localhost:11434")
# Primary LLM (Ollama) model name. Example: "gemma4"
LLM_MODEL       = os.environ.get("CLEO_MODEL", "gemma4")

# Optional fallback LLM (Gemini)
GEMINI_API_KEY = os.environ.get("GEMINI_API_KEY", "")
GEMINI_MODEL   = os.environ.get("GEMINI_MODEL", "gemini-2.5-flash")
MISSION_MAX_STEPS = 10   # max steps before giving up on a mission

VALID_ACTIONS  = [
    "walk_forward", "turn_left", "turn_right",
    "stop", "complete", "speak", "set_mode",
    "dance", "wave",
]

# --- Voice ---
WHISPER_MODEL    = "tiny.en"
TTS_LANGUAGE     = "en"
IDLE_DANCE_TIMEOUT  = 30   # seconds of silence before dancing
ELEVENLABS_API_KEY  = os.environ.get("ELEVENLABS_API_KEY", "")
ELEVENLABS_VOICE_ID = os.environ.get("ELEVENLABS_VOICE_ID", "JBFqnCBsd6RMkjVDRZzb")  # default: George
ELEVENLABS_MODEL    = "eleven_flash_v2_5"
MIC_SAMPLE_RATE       = 16000
MIC_DEVICE_INDEX      = None   # None = default USB mic
MIC_SILENCE_THRESHOLD = 0.01   # RMS below this = silence, skip transcription
MIN_WORDS_TO_PROCESS  = 2      # ignore transcripts shorter than this many words

# --- OLED ---
OLED_WIDTH       = 128
OLED_HEIGHT      = 64
OLED_I2C_ADDRESS = 0x3C
OLED_DRIVER      = "sh1106"   # "sh1106" or "ssd1306" — check your display's chip

# --- Module bay ---
PIR_GPIO_PIN     = 17
DHT11_GPIO_PIN   = 27
MODULE_I2C_ADDRESSES = {
    0x44: "environment",  # DHT11 via I2C adapter
}

# --- Known robot modes ---
KNOWN_MODES = ["general", "security", "environment", "search_rescue"]

# --- Display ---
# Camera feed is shown automatically when a monitor/display is detected ($DISPLAY).
# No config needed — it gracefully skips when running headless over SSH.
CAMERA_WINDOW_NAME = "Quadruped — Camera Feed"

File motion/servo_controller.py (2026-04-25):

import config


class _MockServoController:
    """No-op servo controller — prints commands instead of touching hardware."""

    def set_angle(self, joint_name: str, angle: float):
        print(f"[MOCK] {joint_name} → {angle:.1f}°")

    def set_pose(self, pose: dict):
        for joint, angle in pose.items():
            self.set_angle(joint, angle)

    def stand(self):
        print("[MOCK] stand()")
        self.set_pose(config.STAND_POSE)

    def relax(self):
        print("[MOCK] relax()")


class _RealServoController:
    def __init__(self):
        import board
        import busio
        from adafruit_pca9685 import PCA9685
        from adafruit_motor import servo

        i2c = busio.I2C(board.SCL, board.SDA)
        self.pca = PCA9685(i2c, address=config.PCA9685_ADDRESS)
        self.pca.frequency = config.PWM_FREQUENCY
        self.servos = {
            name: servo.Servo(self.pca.channels[ch],
                              min_pulse=500, max_pulse=2500)
            for name, ch in config.SERVO_CHANNELS.items()
        }

    def set_angle(self, joint_name: str, angle: float):
        lo, hi = config.SERVO_LIMITS.get(joint_name, (0, 180))
        angle = max(lo, min(hi, angle))
        self.servos[joint_name].angle = angle

    def set_pose(self, pose: dict):
        for joint, angle in pose.items():
            self.set_angle(joint, angle)

    def stand(self):
        self.set_pose(config.STAND_POSE)

    def relax(self):
        for s in self.servos.values():
            s.angle = None  # de-energize all servos


def ServoController():
    if config.MOCK_SERVOS:
        return _MockServoController()
    return _RealServoController()

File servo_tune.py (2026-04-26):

import board, busio
from adafruit_pca9685 import PCA9685
from adafruit_motor import servo as servo_lib

i2c = busio.I2C(board.SCL, board.SDA)
pca = PCA9685(i2c, address=0x40)
pca.frequency = 50

channels = [
    ('front_right_hip  (R1)', 0),
    ('front_right_knee (R2)', 11),
    ('front_left_hip   (L1)', 2),
    ('front_left_knee  (L2)', 3),
    ('rear_right_knee  (R4)', 4),
    ('rear_right_hip   (R3)', 12),
    ('rear_left_hip    (L3)', 9),
    ('rear_left_knee   (L4)', 7),
]

print('Servo tuner — enter angles to test, "n" for next servo, "q" to quit')

for name, ch in channels:
    print(f'\n--- Channel {ch}: {name} ---')
    s = servo_lib.Servo(pca.channels[ch], min_pulse=500, max_pulse=2500)
    angle = 90
    s.angle = angle
    print('Starting at 90. Enter angle (0-180) or "n" for next:')
    while True:
        val = input(f'  angle [{angle}]: ').strip()
        if val == 'q':
            pca.deinit()
            exit()
        if val == 'n':
            s.angle = None
            break
        try:
            angle = max(0, min(180, int(val)))
            s.angle = angle
        except ValueError:
            pass

pca.deinit()
print('Done')

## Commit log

2026-04-25 CAD added
    [Battery.ipt, Bottom-Cover-v117.stl, Internal frame.ipt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]
2026-04-26 main and setup fix
    [config.py, servo_tune.py]
